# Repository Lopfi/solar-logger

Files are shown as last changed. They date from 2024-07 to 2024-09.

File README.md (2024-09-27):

# Solar Logger

This is a simple box with an ESP32 with a LC12S, build to replace a DataBox24G from All of Solar, which communicates with a solar inverter to collect data on power generation.

pcb

All configuration is in `/firmware/include/config-example.h` just change the values to your needs and rename it to `config.h`.

For more information on how the hardware works and how I did the reverse engineering visit the hackaday project [here](https://hackaday.io/project/186606-solar-inverter-datalogger-improvements).

If anyone is interested in a the PCB with LC12S and ESP32 for easy communication with the panel and integration into any smarthome system feel free to contact me.

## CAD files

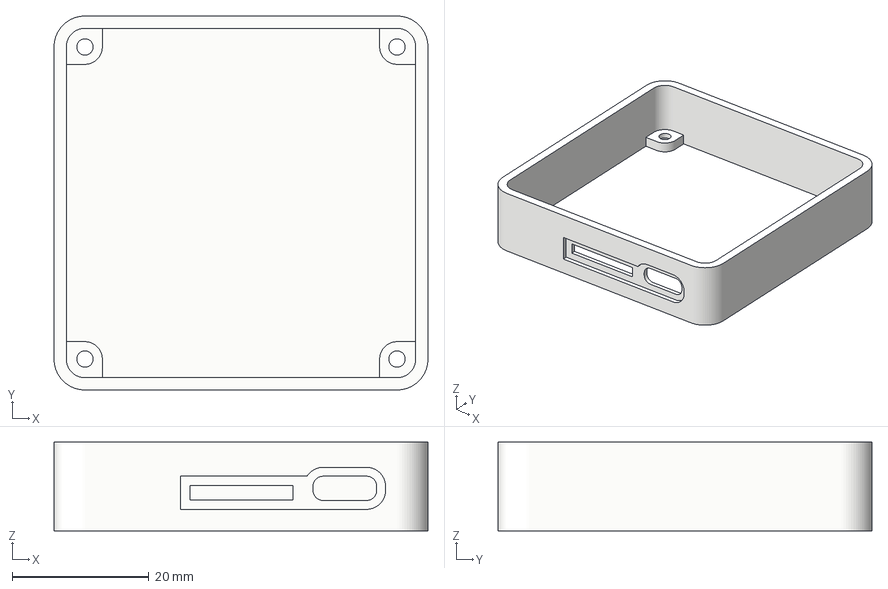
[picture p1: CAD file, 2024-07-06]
case/Bottom.3mf
54.8 x 54.8 x 13.0 mm

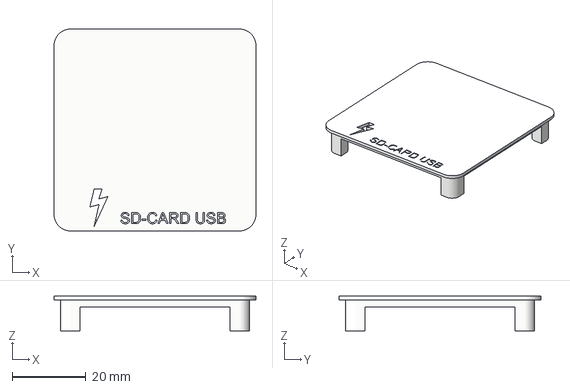
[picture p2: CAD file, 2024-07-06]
case/Top.3mf
54.8 x 54.8 x 9.40 mm

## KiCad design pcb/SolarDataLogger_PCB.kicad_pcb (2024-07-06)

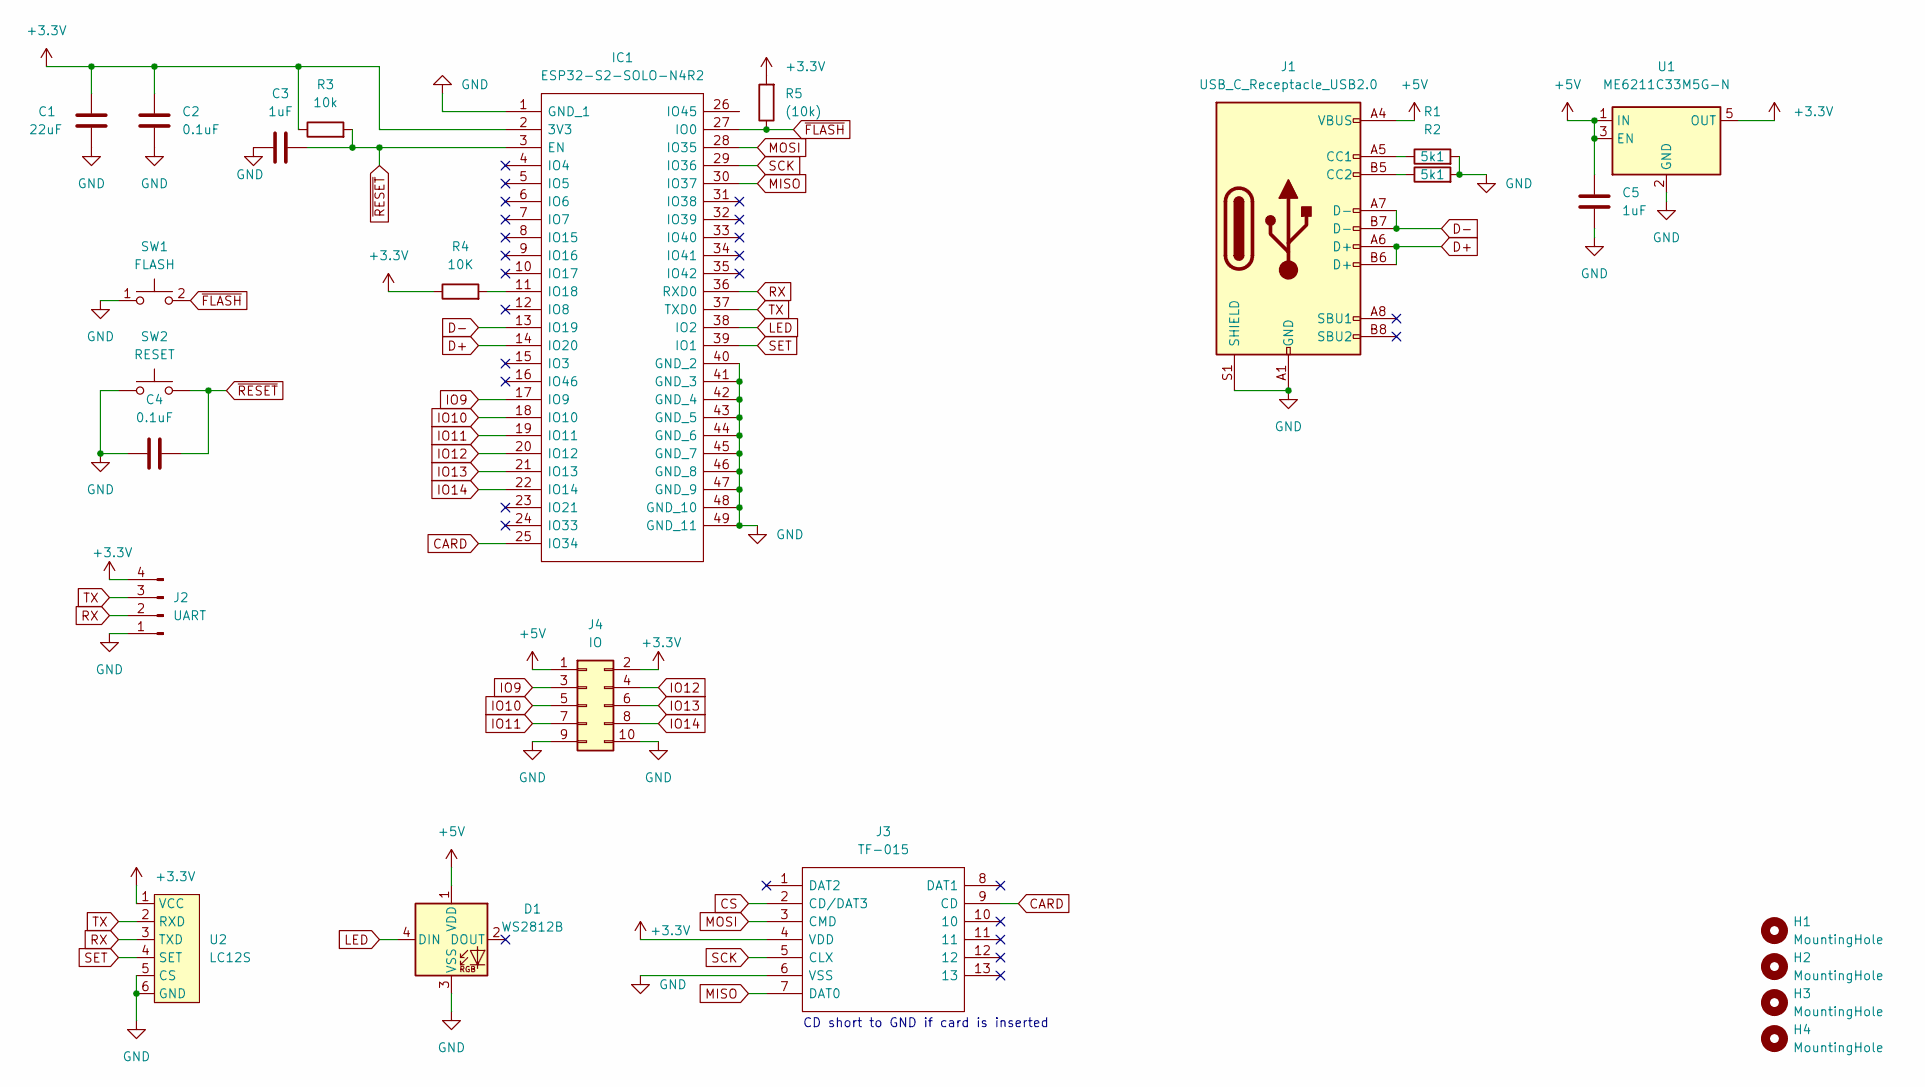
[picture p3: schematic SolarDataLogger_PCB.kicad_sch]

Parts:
C1: 22uF; C_0805_2012Metric_Pad1.18x1.45mm_HandSolder
C2, C4: 0.1uF; C_0805_2012Metric_Pad1.18x1.45mm_HandSolder
C3, C5: 1uF; C_0805_2012Metric_Pad1.18x1.45mm_HandSolder
D1: WS2812B; LED_WS2812B_PLCC4_5.0x5.0mm_P3.2mm
H1, H2, H3, H4: MountingHole; MountingHole_2.2mm_M2
IC1: ESP32-S2-SOLO-N4R2; ESP32S2SOLON4R2; Manufacturer_Part_Number ESP32-S2-SOLO-N4R2; Mouser Part Number 356-ESP32-S2SOLON4R2
J1: USB_C_Receptacle_USB2.0; USB_C_Receptacle_HRO_TYPE-C-31-M-12
J2: UART; PinHeader_1x04_P2.54mm_Vertical
J3: TF-015; TF015; Manufacturer_Part_Number TF-015
J4: IO; PinHeader_2x05_P2.54mm_Vertical
R1, R2: 5k1; R_0805_2012Metric_Pad1.20x1.40mm_HandSolder
R3: 10k; R_0805_2012Metric_Pad1.20x1.40mm_HandSolder
R4: 10K; R_0805_2012Metric_Pad1.20x1.40mm_HandSolder
R5: (10k); R_0805_2012Metric_Pad1.20x1.40mm_HandSolder
SW1: FLASH; TS1187ABAB
SW2: RESET; TS1187ABAB
U1: ME6211C33M5G-N; SOT-23-5_HandSoldering
U2: LC12S

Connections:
+3.3V: C1.2, C2.2, IC1.2 (3V3), J2.4, J3.4 (VDD), J4.2, R3.1, R4.1, R5.2, U1.5 (OUT), U2.1 (VCC)
+5V: C5.1, D1.1 (VDD), J1.A4 (VBUS), J1.A9 (VBUS), J1.B4 (VBUS), J1.B9 (VBUS), J4.1, U1.1 (IN), U1.3 (EN)
CARD: IC1.25 (IO34), J3.9 (CD)
CS: J3.2 (CD/DAT3)
D+: IC1.14 (IO20), J1.A6 (D+), J1.B6 (D+)
D-: IC1.13 (IO19), J1.A7 (D-), J1.B7 (D-)
GND: C1.1, C2.1, C3.1, C4.2, C5.2, D1.3 (VSS), IC1.1 (GND_1), IC1.40 (GND_2), IC1.41 (GND_3), IC1.42 (GND_4), IC1.43 (GND_5), IC1.44 (GND_6), IC1.45 (GND_7), IC1.46 (GND_8), IC1.47 (GND_9), IC1.48 (GND_10), IC1.49 (GND_11), J1.A1 (GND), J1.A12 (GND), J1.B1 (GND), J1.B12 (GND), J1.S1 (SHIELD), J2.1, J3.6 (VSS), J4.9, J4.10, R1.2, R2.2, SW1.1, SW2.1, U1.2 (GND), U2.5 (CS), U2.6 (GND)
IO9: IC1.17 (IO9), J4.3
IO10: IC1.18 (IO10), J4.5
IO11: IC1.19 (IO11), J4.7
IO12: IC1.20 (IO12), J4.4
IO13: IC1.21 (IO13), J4.6
IO14: IC1.22 (IO14), J4.8
LED: D1.4 (DIN), IC1.38 (IO2)
MISO: IC1.30 (IO37), J3.7 (DAT0)
MOSI: IC1.28 (IO35), J3.3 (CMD)
unnamed: IC1.11 (IO18), R4.2
unnamed: J1.A5 (CC1), R1.1
unnamed: J1.B5 (CC2), R2.1
RX: IC1.36 (RXD0), J2.2, U2.3 (TXD)
SCK: IC1.29 (IO36), J3.5 (CLX)
SET: IC1.39 (IO1), U2.4 (SET)
TX: IC1.37 (TXD0), J2.3, U2.2 (RXD)
~FLASH: IC1.27 (IO0), R5.1, SW1.2
~RESET: C3.2, C4.1, IC1.3 (EN), R3.2, SW2.2

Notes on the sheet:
CD short to GND if card is inserted

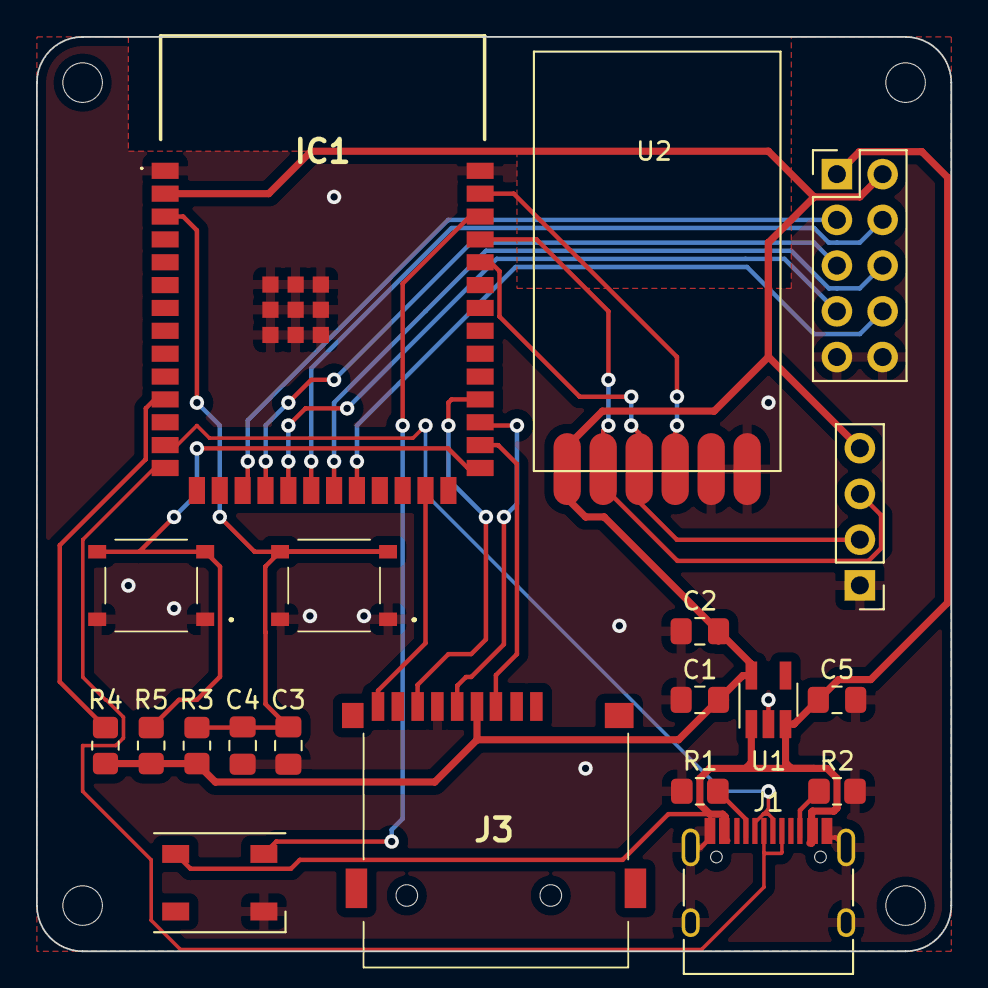
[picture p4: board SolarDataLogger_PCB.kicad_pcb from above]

Board: 2 copper layers, 50.8 x 50.8 mm, 24 parts (0 on the bottom side), 24 nets.

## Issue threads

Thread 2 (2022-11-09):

Maybe Additional Info2

Member0815, 2022-11-09:
measured again today with following findings:
Command Turn On: 43 C1 BoxID AreaID InverterID 00 00 00 01 Checksum
Command Turn Off: 43 C1 BoxID AreaID InverterID 00 00 00 02 Checksum
Command Reboot Inverter: 43 C1 BoxID AreaID InverterID 00 00 00 03 Checksum
Command Adjust PowerGrade: 43 C3 BoxID AreaID InverterID 00 00 00 xx Checksum, where xx is required powergrade in percent from 01..64

Checksum is calculated: Add  all bytes from 43 to last byte of telegram and use low byte as checksum, ignoring high byte.

The shown values AC-power or DC-power in NETMS are not found inside the answer telegram from SG600, but strictly calculated from product current and voltage

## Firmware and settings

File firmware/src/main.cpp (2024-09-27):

#include <Arduino.h>
#include <WiFiMulti.h>
#include <InfluxDbClient.h>
#include <FastLED.h>
#include <NETSGPClient.h>

#include "config.h"

#define debugSerial Serial
#define clientSerial Serial1

NETSGPClient inverter(clientSerial, PROG_PIN); /// NETSGPClient instance

WiFiMulti wifiMulti;

CRGB leds[NUM_LEDS];

InfluxDBClient influx(INFLUXDB_URL, INFLUXDB_ORG, INFLUXDB_BUCKET, INFLUXDB_TOKEN);

// Data point
Point sensor("inverter_data");

boolean newData = false;
int lastTx;
int lastRx;
int attemps = 0;

void setup() {

  FastLED.addLeds<NEOPIXEL, DATA_PIN>(leds, NUM_LEDS);  // GRB ordering is assumed
  FastLED.setBrightness(5);
  leds[0] = CRGB::Red;
  FastLED.show();

  debugSerial.begin(115200);
  clientSerial.begin(9600, SERIAL_8N1, RX_PIN, TX_PIN);

  delay(500);

  Serial.println("Starting...");

  // Connect WiFi
  Serial.println("Connecting to WiFi");
  WiFi.mode(WIFI_STA);
  wifiMulti.addAP(WIFI_SSID, WIFI_PASSWORD);
  while (wifiMulti.run() != WL_CONNECTED) {
    Serial.print(".");
    delay(500);
  }
  Serial.println();
  leds[0] = CRGB::Yellow;
  FastLED.show();

  delay(1000);

  // Make sure the RF module is set to the correct settings
  if (!inverter.setDefaultRFSettings())
  {
      debugSerial.println("Could not set RF module to default settings");
      leds[0] = CRGB::Yellow;
      FastLED.show();
  }

  // Check server connection
  if (influx.validateConnection()) {
    Serial.print("Connected to InfluxDB: ");
    Serial.println(influx.getServerUrl());
    leds[0] = CRGB::Blue;
    FastLED.show();
  } else {
    Serial.print("InfluxDB connection failed: ");
    Serial.println(influx.getLastErrorMessage());
    leds[0] = CRGB::Red;
    FastLED.show();
  }

  delay(1000);

  lastTx = millis();
  lastRx = millis();

  sensor.clearTags();
  sensor.addTag("INVERTER_ID", String(inverterID));
  sensor.addTag("source", "solar-logger");
}

void writeToDB() {
    // Print what are we exactly writing
  Serial.print("Writing: ");
  Serial.println(influx.pointToLineProtocol(sensor));
  // If no Wifi signal, try to reconnect it
  if (wifiMulti.run() != WL_CONNECTED) {
    Serial.println("Wifi connection lost");
  }
  // Write point
  if (!influx.writePoint(sensor)) {
    Serial.print("InfluxDB write failed: ");
    Serial.println(influx.getLastErrorMessage());
  }
}

uint32_t lastSendMillis = 0;
void loop() {
  const uint32_t currentMillis = millis();
  if (currentMillis - lastSendMillis > 60000) {
    lastSendMillis = currentMillis;
    attemps++;
    debugSerial.println("");
    debugSerial.println("Sending request now");

    const NETSGPClient::InverterStatus status = inverter.getStatus(inverterID);
    if (status.valid) {
      leds[0] = CRGB::Green;
      FastLED.show();
      debugSerial.println("*********************************************");
      debugSerial.println("Received Inverter Status");
      debugSerial.print("Device: ");
      debugSerial.println(status.deviceID, HEX);
      debugSerial.println("Status: " + String(status.state));
      debugSerial.println("DC_Voltage: " + String(status.dcVoltage) + "V");
      debugSerial.println("DC_Current: " + String(status.dcCurrent) + "A");
      debugSerial.println("DC_Power: " + String(status.dcPower) + "W");
      debugSerial.println("AC_Voltage: " + String(status.acVoltage) + "V");
      debugSerial.println("AC_Current: " + String(status.acCurrent) + "A");
      debugSerial.println("AC_Power: " + String(status.acPower) + "W");
      debugSerial.println("Power gen total: " + String(status.totalGeneratedPower));
      debugSerial.println("Temperature: " + String(status.temperature));
      
      // Store measured value into point
      sensor.clearFields();
      sensor.addField("STATUS", status.state);
      sensor.addField("VDC", status.dcVoltage);
      sensor.addField("IDC", status.dcCurrent);
      sensor.addField("PDC", status.dcPower);
      sensor.addField("VAC", status.acVoltage);
      sensor.addField("IAC", status.acCurrent);
      sensor.addField("PAC", status.acPower);
      sensor.addField("TOTAL_GEN", status.totalGeneratedPower);
      sensor.addField("TEMP", status.temperature);

      // Write point to InfluxDB
      writeToDB();
      attemps = 0;

    } else if (attemps > 3) {
      Serial.println("No response from inverter");
      leds[0] = CRGB::Yellow;
      FastLED.show();

      // Store measured value into point
      sensor.clearFields();
      sensor.addField("STATUS", 0);
      sensor.addField("VDC", 0.0);
      sensor.addField("IDC", 0.0);
      sensor.addField("PDC", 0.0);
      sensor.addField("VAC", 0.0);
      sensor.addField("IAC", 0.0);
      sensor.addField("PAC", 0.0);
      sensor.addField("TOTAL_GEN", 0.0);
      sensor.addField("TEMP", 0);

      // Write point to InfluxDB
      writeToDB();
      attemps = 0;
    }
  }
}

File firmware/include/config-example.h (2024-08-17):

//WiFi
//---------------------------------------------------------
// WiFi AP SSID
#define WIFI_SSID "ssid"
// WiFi password
#define WIFI_PASSWORD "password" 

// InfluxDB
//---------------------------------------------------------
// InfluxDB  server url.
// E.g. http://192.168.1.48:8086, 
#define INFLUXDB_URL "influxdb-url"
// InfluxDB 2 server or cloud API authentication token
#define INFLUXDB_TOKEN "toked-id"
// InfluxDB 2 organization id
#define INFLUXDB_ORG "org"
// InfluxDB 2 bucket name
#define INFLUXDB_BUCKET "bucket"

// Inverter
//---------------------------------------------------------
// Programming enable pin of RF module
constexpr const uint8_t PROG_PIN = 1;
// RX pin of ESP32 connect to TX of RF module
constexpr const uint8_t RX_PIN = 44;
// TX pin of ESP32 connect to RX of RF module
constexpr const uint8_t TX_PIN = 43;
// Identifier of your inverter (see label on inverter)
constexpr const uint32_t inverterID = 0x38004146;

// LED
//---------------------------------------------------------
// Number of leds in the strip
#define NUM_LEDS 1
// Data pin where the LED strip is connected to
#define DATA_PIN 2

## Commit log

2023-01-27 add esp32s2 board
2024-07-06 add led
2024-07-06 fix pins and serial
    [config-example.h, main.cpp]
2024-07-06 add pcb and casse
    [Bottom.3mf, SolarDataLogger_PCB.kicad_pcb, SolarDataLogger_PCB.kicad_sch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]
2024-07-16 show led status first
2024-08-17 switch to NETSGPClient library
